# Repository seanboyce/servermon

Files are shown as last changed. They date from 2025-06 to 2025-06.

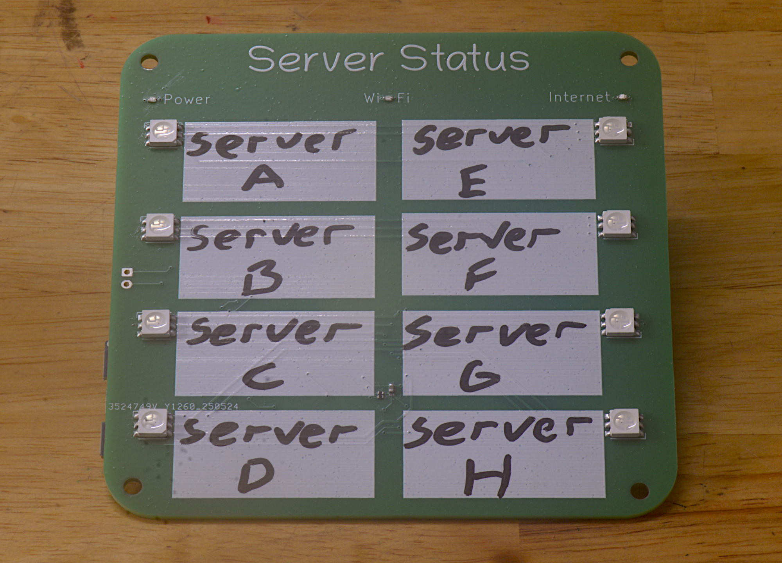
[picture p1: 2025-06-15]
servermon_generic.JPG

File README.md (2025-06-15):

# An ESP8266-based Server Monitor
This ESP8266-based server monitor PCB displays the status of up to 8 servers with RGB LEDs. If it receives HTTP 200, the LED will turn green. If it receives anything else, it will turn yellow the first time and red subsequent times.

The big white patches of silkscreen are there for you to write the server names on. You can use whiteboard markers if they change often, permanent marker (clean off with ethanol) or labels.

The firmware is just an Arduino sketch. I've done it this way because Arduino is popular, so this is the easiest for most people to modify.

It will send the HTTP GET requests with https, but will not verify the certificates. This is by design -- there's not much memory on an ESP8266, and you'd have to go through the hassle of loading the certificates onto the MCU storage manually. This is also why it only sends one request at a time instead of creating a http client and then sending all 9. That would often causes out-of-memory errors!

# BOM
- 1x ESP8266 mini-D1 pro. The non-pro version will work, but you'll have to solder in header pins, then solder those directly the pads on the board. The Pro version is lower profile and solders flush to the board. 
- 1x TM1640 LED driver
- 8x 5050 RGB LED
- 1x 1411 Tantalum capacitor 100uf 6.3V (you can use electrolytic but it will be bigger)
- 1x 0603 0.1uF ceramic capacitor 50V
- 4x 0402 10k ohm resistor
- 1x 0402 20k ohm resistor (this is for the power LED to make it similar brightness to the others. If you don't care, you can use another 10k)
- 3x 0603 red LED (or any color that works under ESP8266 GPIO HIGH voltage)
- Antenna for mini-D1 Pro (optional)
- 1x PCB

# Total Cost

In Asia, about VND 164.550 ($6.31) without antenna or 190.000 (7.29) with antenna (board included, assuming you make 5 units). In the West probably double, but it's still pretty cheap!

# Photo

Photo of the completed server monitor

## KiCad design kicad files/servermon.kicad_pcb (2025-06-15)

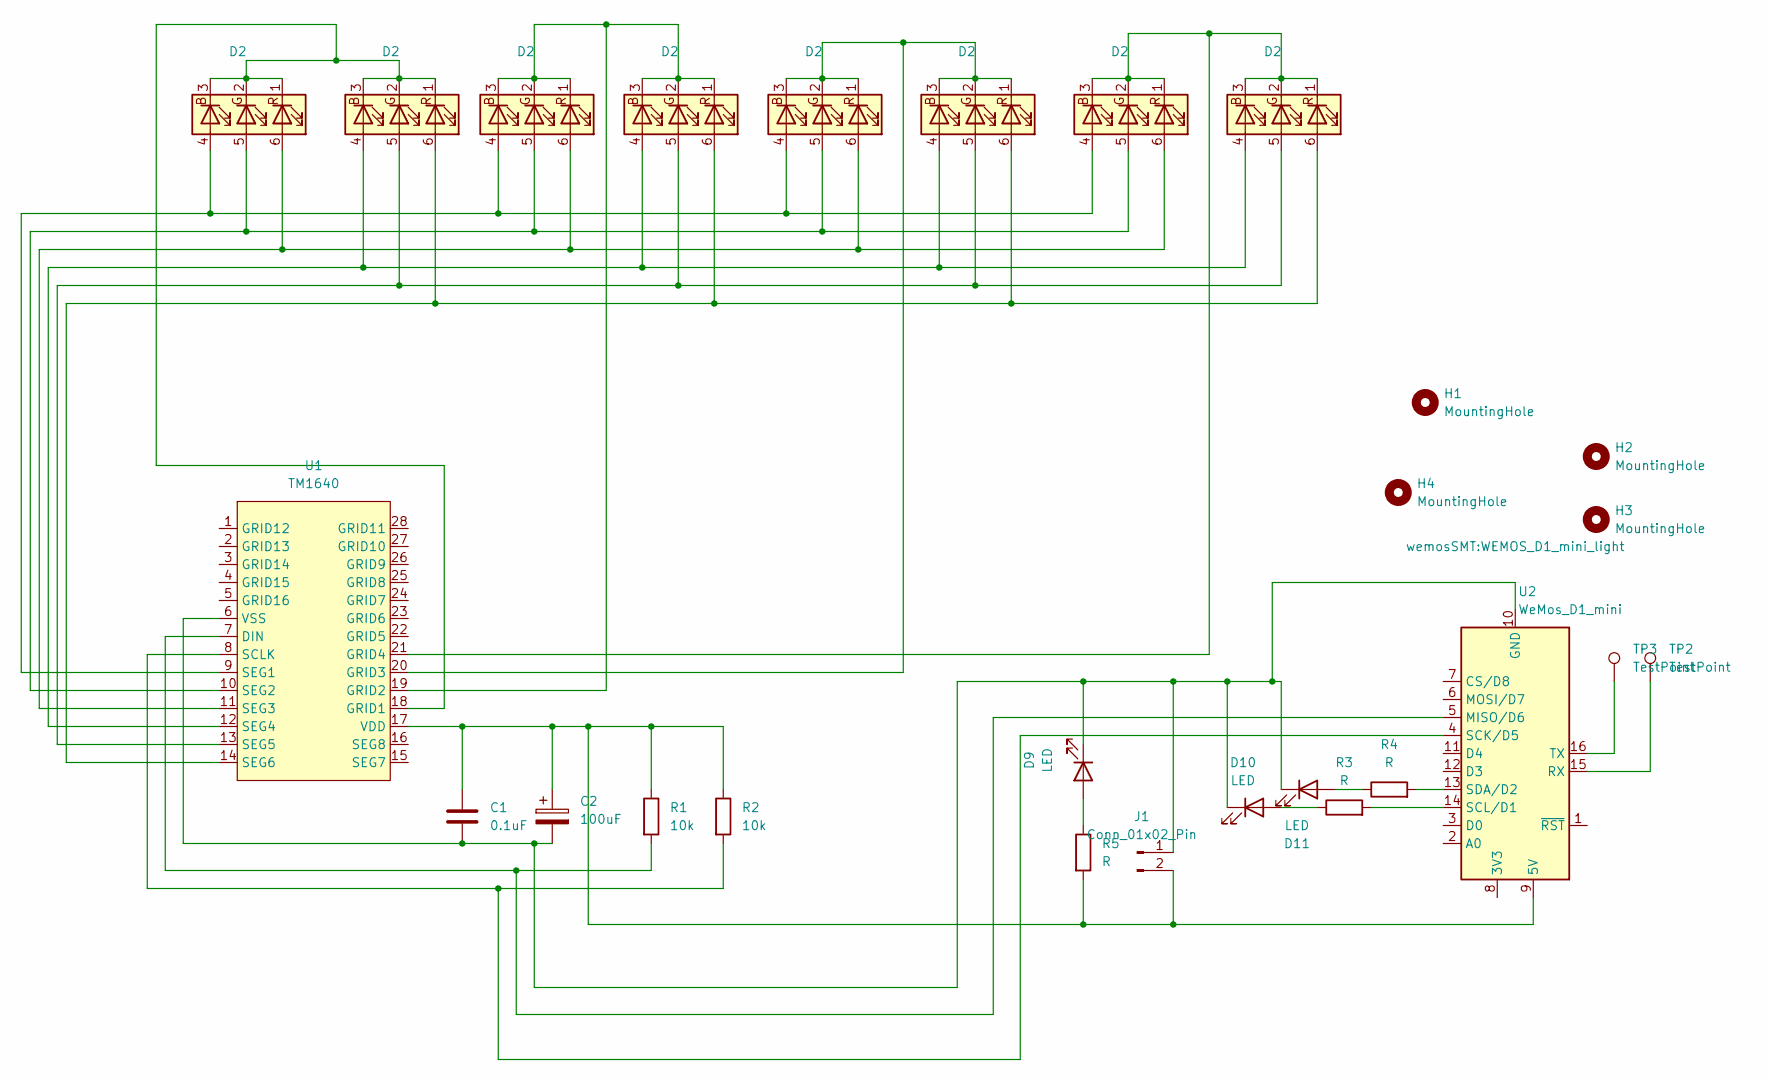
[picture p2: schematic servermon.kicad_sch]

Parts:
C1: 0.1uF; C_0603_1608Metric
C2: 100uF; CP_EIA-3528-12_Kemet-T
D1, D2, D3, D4, D5, D6, D7, D8: D2; LED_RGB_5050-6
D9, D10, D11: LED; LED_0603_1608Metric
H1, H2, H3, H4: MountingHole; MountingHole_3.2mm_M3
J1: Conn_01x02_Pin; JST_EH_B2B-EH-A_1x02_P2.50mm_Vertical
R1, R2: 10k; R_0402_1005Metric
R3, R4, R5: R; R_0402_1005Metric
TP2, TP3: TestPoint; TestPoint_Pad_D2.0mm
U1: TM1640
U2: WeMos_D1_mini; WEMOS_D1_mini_light

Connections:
unnamed: D1.4 (BA), D3.4 (BA), D5.4 (BA), D7.4 (BA), U1.9 (SEG1)
unnamed: D1.1 (RK), D1.2 (GK), D1.3 (BK), D2.1 (RK), D2.2 (GK), D2.3 (BK), U1.18 (GRID1)
unnamed: D1.5 (GA), D3.5 (GA), D5.5 (GA), D7.5 (GA), U1.10 (SEG2)
unnamed: D1.6 (RA), D3.6 (RA), D5.6 (RA), D7.6 (RA), U1.11 (SEG3)
unnamed: D2.4 (BA), D4.4 (BA), D6.4 (BA), D8.4 (BA), U1.12 (SEG4)
unnamed: D2.5 (GA), D4.5 (GA), D6.5 (GA), D8.5 (GA), U1.13 (SEG5)
unnamed: D2.6 (RA), D4.6 (RA), D6.6 (RA), D8.6 (RA), U1.14 (SEG6)
unnamed: D3.1 (RK), D3.2 (GK), D3.3 (BK), D4.1 (RK), D4.2 (GK), D4.3 (BK), U1.19 (GRID2)
unnamed: D5.1 (RK), D5.2 (GK), D5.3 (BK), D6.1 (RK), D6.2 (GK), D6.3 (BK), U1.20 (GRID3)
unnamed: D7.1 (RK), D7.2 (GK), D7.3 (BK), D8.1 (RK), D8.2 (GK), D8.3 (BK), U1.21 (GRID4)
unnamed: D9.2 (A), R5.1
unnamed: D10.2 (A), R3.1
unnamed: C1.2, C2.2, D9.1 (K), D10.1 (K), D11.1 (K), J1.1, U1.6 (VSS), U2.10 (GND)
unnamed: D11.2 (A), R4.1
unnamed: C1.1, C2.1, J1.2, R1.1, R2.1, R5.2, U1.17 (VDD), U2.9 (5V)
unnamed: R1.2, U1.7 (DIN), U2.5 (MISO/D6)
unnamed: R2.2, U1.8 (SCLK), U2.4 (SCK/D5)
unnamed: TP2.1, U2.15 (RX)
unnamed: R3.2, U2.14 (SCL/D1)
unnamed: R4.2, U2.13 (SDA/D2)
unnamed: TP3.1, U2.16 (TX)

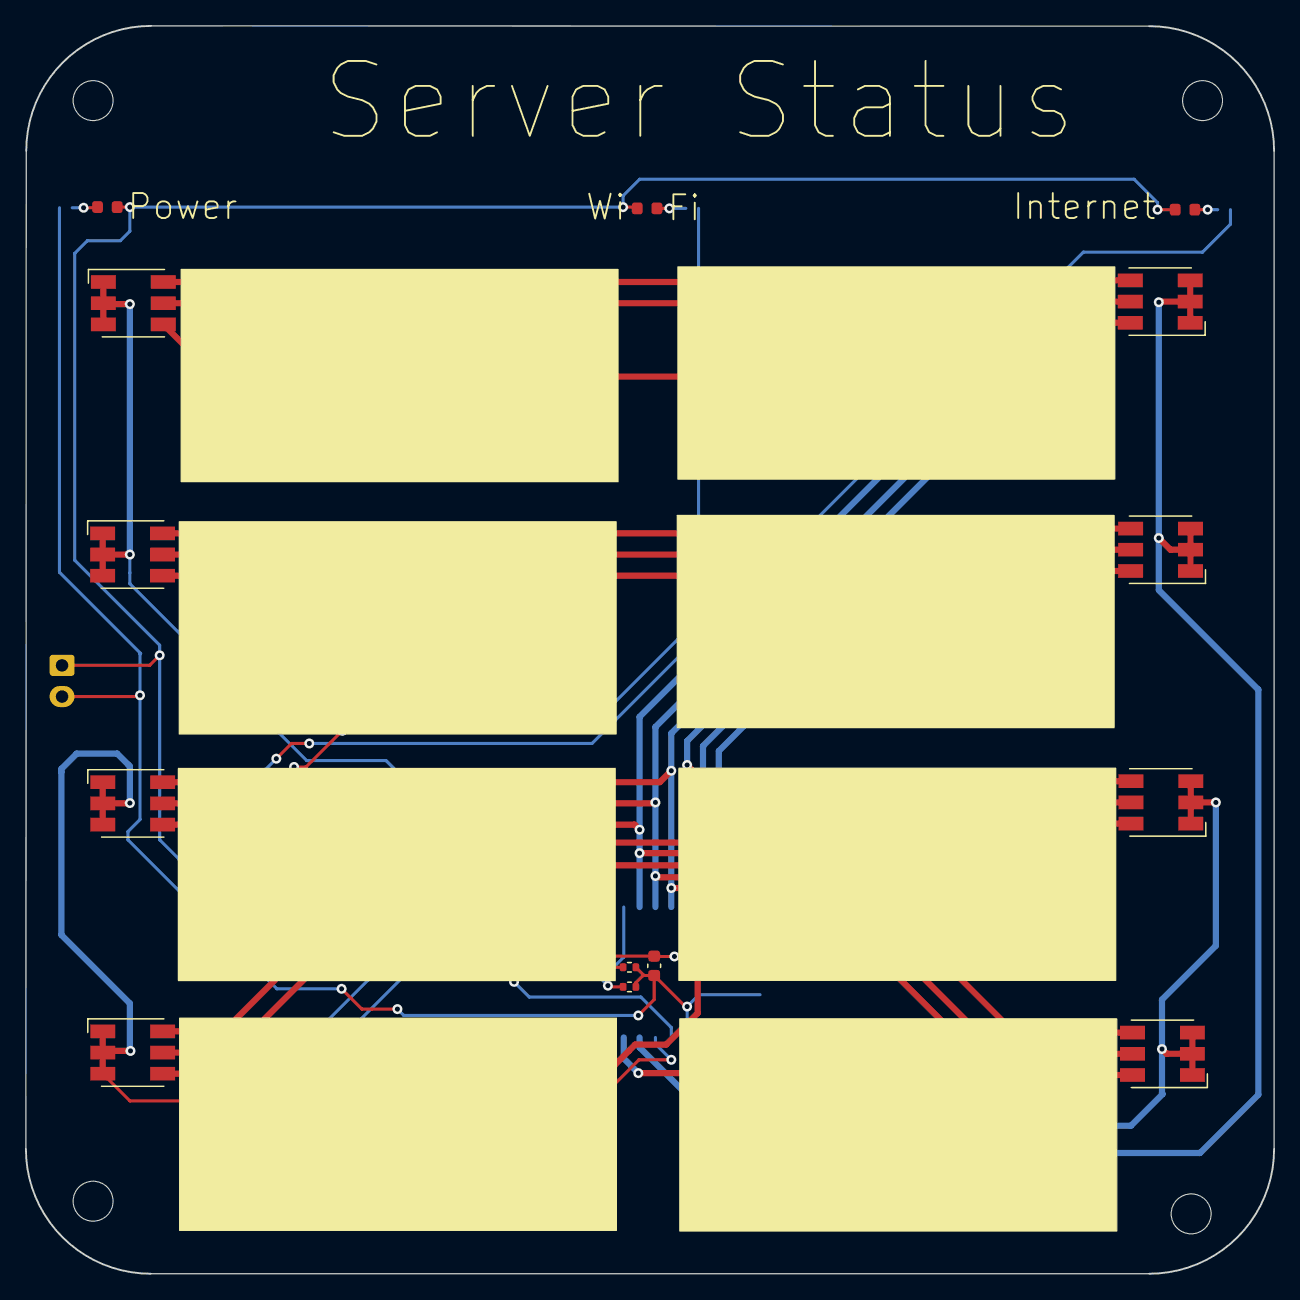
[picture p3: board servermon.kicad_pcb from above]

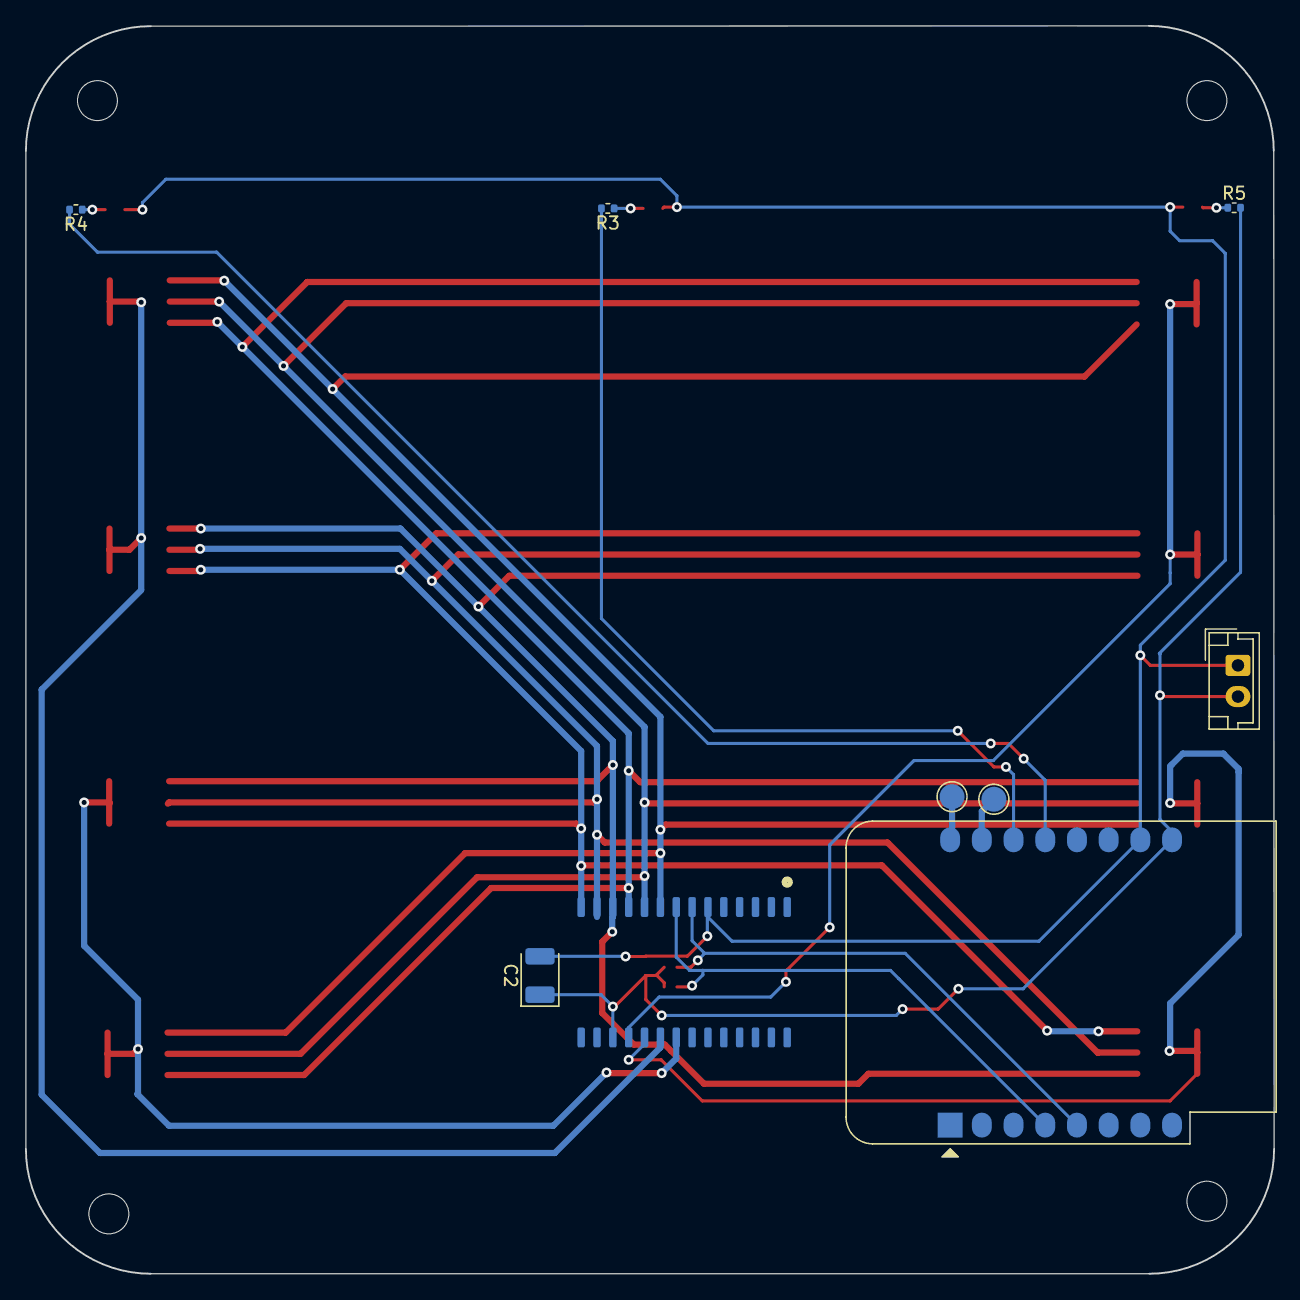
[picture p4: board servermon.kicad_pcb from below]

Board: 2 copper layers, 100.0 x 100.0 mm, 27 parts (9 on the bottom side), 21 nets.

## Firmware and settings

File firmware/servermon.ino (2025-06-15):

#include <ESP8266WiFi.h>
#include <ESP8266WiFiMulti.h>
#include <ESP8266HTTPClient.h>
#include <TM1640.h>
#include <TM16xxMatrix.h>
#include <WiFiClientSecureBearSSL.h>

unsigned long lastTime = 0;
// Check every 70 seconds
unsigned long timerDelay = 70000;



// Monitor these 8 servers + 1 for Internet connectivity check. First item in array is for internet connectivity (set to 1.1.1.1 clouflare, but you can use any server)."
#define ARRAYSIZE 9
String servers[ARRAYSIZE] = { "https://one.one.one.one/", "https://server1.com", "https://server2.com","https://server3.com", "https://server4.com", "https://server5.com", "https://server6.com","https://server7.com", "https://server8.com" };
// save last state to secide if RGB LED should be red or yellow on fail
bool laststate[ARRAYSIZE] = {true,true,true,true,true,true,true,true,true};

// TM1640 Settings. D5=14=SCLK, D6=12=DATA
TM1640 module(12, 14);
// We use 6 rows (SEG1-6) and 4 columns (GRID 1-4). This is 8 RGB LEDs
#define MATRIX_NUMCOLUMNS 6
#define MATRIX_NUMROWS 4

TM16xxMatrix matrix(&module, MATRIX_NUMCOLUMNS, MATRIX_NUMROWS);    // TM16xx object, columns, rows

ESP8266WiFiMulti WiFiMulti;


void setup() {
//Start LED tests!
// Wi-Fi LED
pinMode(5, OUTPUT);
digitalWrite(5, HIGH);
delay(250);
digitalWrite(5, LOW);
// Internet Connectivity LED
pinMode(4, OUTPUT);
digitalWrite(4, HIGH);
delay(250);
digitalWrite(4, LOW);
    // Blink all on startup as LED test
  for(int i=0; i<(MATRIX_NUMROWS-1); i++)
  {
    for(int j=0; j<MATRIX_NUMCOLUMNS; j++)
    {
        matrix.setPixel(i,j, true);
        delay(200);
        matrix.setPixel(i,j, false);
    }
  }
// Last two LEDS are swapped columns to make the boards easier to route.
for(int i=3; i<MATRIX_NUMROWS; i++)
  {
    for(int j=0; j<MATRIX_NUMCOLUMNS; j++)
    {
        matrix.setPixel(i,5-j, true);
        delay(200);
        matrix.setPixel(i,5-j, false);
    }
  }
  Serial.begin(115200);

// LED tests complete. You should have seen all LEDs light up sequentially.

  // the true work begins. We start by connecting to a WiFi network

  Serial.println();
  Serial.println();
  Serial.print("Connecting to Wi-Fi");

  /* Explicitly set the ESP8266 to be a WiFi-client, otherwise, it by default,
     would try to act as both a client and an access-point and could cause
     network-issues with your other WiFi-devices on your WiFi-network. */
  WiFi.mode(WIFI_STA);
  WiFiMulti.addAP("your_network", "your_password");

  while (WiFiMulti.run() != WL_CONNECTED) {
    delay(500);
    Serial.print(".");
  }
  // Set Wi-Fi LED = on
  digitalWrite(5, HIGH);
  Serial.println("");
  Serial.println("WiFi connected");

}

void loop() {
    std::unique_ptr<BearSSL::WiFiClientSecure>client(new BearSSL::WiFiClientSecure);

    // Ignore SSL certificate validation, to save memory.
    client->setInsecure();

// Send an HTTP POST request depending on timerDelay
  if ((millis() - lastTime) > timerDelay) {
    //Check WiFi connection status
    if(WiFi.status()== WL_CONNECTED){
      //WiFiClient client;
      for(int i=0; i<9; i++){
        HTTPClient https;
        // Yo ucan remove printing to serial here if you want, but it's useful for debug.
        Serial.println(servers[i]);
        https.begin(*client, servers[i].c_str());
        int httpResponseCode = https.GET();
        Serial.println(httpResponseCode);
        https.end();
        // The case/switch below is sort of gross. There are more elegant ways to do this, however this one is the easiest for beginenrs to modify.
        if (httpResponseCode==200) {
          switch (i){
          case 0:
              digitalWrite(4, HIGH);
              break;
          case 1:
              matrix.setPixel(0,1, false); // Red
              matrix.setPixel(0,0, false); // Blue
              matrix.setPixel(0,2, true); // Green
              laststate[i] = true;
              break;
          case 2:
              matrix.setPixel(0,4, false); // 
              matrix.setPixel(0,3, false); // 
              matrix.setPixel(0,5, true); // 
              laststate[i] = true;
              break;
          case 3:
              matrix.setPixel(1,1, false); // 
              matrix.setPixel(1,0, false); // 
              matrix.setPixel(1,2, true); // 
              laststate[i] = true;
              break;
          case 4:
              matrix.setPixel(1,4, false); // 
              matrix.setPixel(1,3, false); // 
              matrix.setPixel(1,5, true); // 
              laststate[i] = true;
              break;
          case 5:
              matrix.setPixel(2,1, false); // 
              matrix.setPixel(2,0, false); // 
              matrix.setPixel(2,2, true); // 
              laststate[i] = true;
              break;
          case 6:
              matrix.setPixel(2,4, false); // 
              matrix.setPixel(2,3, false); // 
              matrix.setPixel(2,5, true); // 
              laststate[i] = true;
              break;
          case 7:
              matrix.setPixel(3,1, false); // 
              matrix.setPixel(3,0, false); // 
              matrix.setPixel(3,2, true); // 
              laststate[i] = true;
              break;
          case 8:
              matrix.setPixel(3,4, false); // 
              matrix.setPixel(3,3, false); // 
              matrix.setPixel(3,5, true); // 
              laststate[i] = true;
              break;
          }
      }
      else {
        switch (i){
          case 0:
              digitalWrite(4, LOW);
              break;
          case 1:
              if (laststate[i] == true){
                  matrix.setPixel(0,1, true); // Red, Last state was HTTP 200 so we turn yellow
                  matrix.setPixel(0,0, false); // Blue
                  matrix.setPixel(0,2, true); // Green
                  laststate[i] = false; // save state
              }
              else{
                  matrix.setPixel(0,1, true);
                  matrix.setPixel(0,0, false); 
                  matrix.setPixel(0,2, false); // Last state was not HTTP 200, so we turn red.
              }

              break;  
          case 2:
              if (laststate[i] == true){
                  matrix.setPixel(0,4, true); // 
                  matrix.setPixel(0,3, false); // 
                  matrix.setPixel(0,5, true); // 
                  laststate[i] = false; // 
              }
              else{
                  matrix.setPixel(0,4, true);
                  matrix.setPixel(0,3, false); 
                  matrix.setPixel(0,5, false); //   
              }

              break;  
          case 3:
              if (laststate[i] == true){
                  matrix.setPixel(1,1, true); // 
                  matrix.setPixel(1,0, false); // 
                  matrix.setPixel(1,2, true); // 
                  laststate[i] = false; // 
              }
              else{
                  matrix.setPixel(1,1, true);
                  matrix.setPixel(1,0, false); 
                  matrix.setPixel(1,2, false); //   
              }

              break;  
          case 4:
              if (laststate[i] == true){
                  matrix.setPixel(1,4, true); // 
                  matrix.setPixel(1,3, false); // 
                  matrix.setPixel(1,5, true); // 
                  laststate[i] = false; // 
              }
              else{
                  matrix.setPixel(1,4, true);
                  matrix.setPixel(1,3, false); 
                  matrix.setPixel(1,5, false); //   
              }

              break; 
          case 5:
              if (laststate[i] == true){
                  matrix.setPixel(2,1, true); // 
                  matrix.setPixel(2,0, false); // 
                  matrix.setPixel(2,2, true); // 
                  laststate[i] = false; // 
              }
              else{
                  matrix.setPixel(2,1, true);
                  matrix.setPixel(2,0, false); 
                  matrix.setPixel(2,2, false); //   
              }

              break;  
          case 6:
              if (laststate[i] == true){
                  matrix.setPixel(2,4, true); // 
                  matrix.setPixel(2,3, false); // 
                  matrix.setPixel(2,5, true); // 
                  laststate[i] = false; // 
              }
              else{
                  matrix.setPixel(2,4, true);
                  matrix.setPixel(2,3, false); 
                  matrix.setPixel(2,5, false); //   
              }

              break;  
          case 7:
              if (laststate[i] == true){
                  matrix.setPixel(3,1, true); // 
                  matrix.setPixel(3,0, false); // 
                  matrix.setPixel(3,2, true); // 
                  laststate[i] = false; // 
              }
              else{
                  matrix.setPixel(3,1, true);
                  matrix.setPixel(3,0, false); 
                  matrix.setPixel(3,2, false); //   
              }

              break;  
          case 8:
              if (laststate[i] == true){
                  matrix.setPixel(3,4, true); // 
                  matrix.setPixel(3,3, false); // 
                  matrix.setPixel(3,5, true); // 
                  laststate[i] = false; // 
              }
              else{
                  matrix.setPixel(3,4, true);
                  matrix.setPixel(3,3, false); 
                  matrix.setPixel(3,5, false); //Red   
              }

              break;
          }
        
      }
      }}
      // We don't actually handle what to do on disconnect other than turn off the LEDs to alert you. Yo ucould write a handler for that here. Probably, just restarting the device would be an OK handler. However, I've never had it disconnect. 
    else {
      Serial.println("WiFi Disconnected");
      digitalWrite(5, LOW);
      digitalWrite(4, LOW); // If no Wi-Fi, there's no Internet.
    }
    lastTime = millis();
  }

}

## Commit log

2025-06-15 Add files via upload
    Add KiCAD and production files for the PCB.
    [servermon-B_Cu.gbr, servermon-B_Mask.gbr, servermon-B_Paste.gbr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]
2025-06-15 Update README.md
    Add description, BOM, Cost
